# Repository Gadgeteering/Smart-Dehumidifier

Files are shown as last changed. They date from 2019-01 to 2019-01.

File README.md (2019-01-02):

# Smart-Dehumidifier

This project modifies a Demuidifier into a Smart Dehumidifier so that it is automatically turned on when it is predicted that condensation will form on a window pane.


More details of project are available here

https://www.instructables.com/id/Dehumidifier/

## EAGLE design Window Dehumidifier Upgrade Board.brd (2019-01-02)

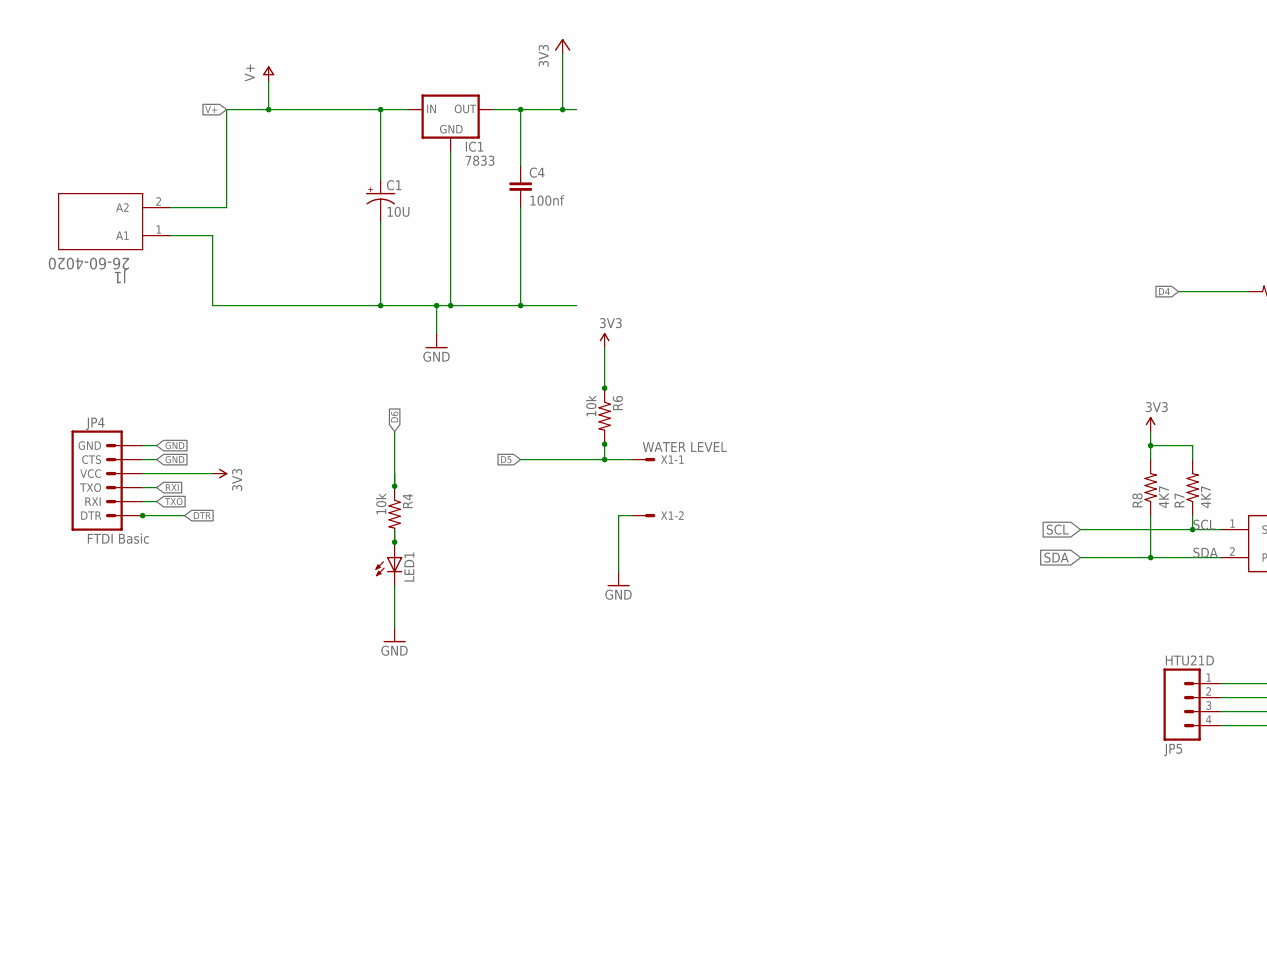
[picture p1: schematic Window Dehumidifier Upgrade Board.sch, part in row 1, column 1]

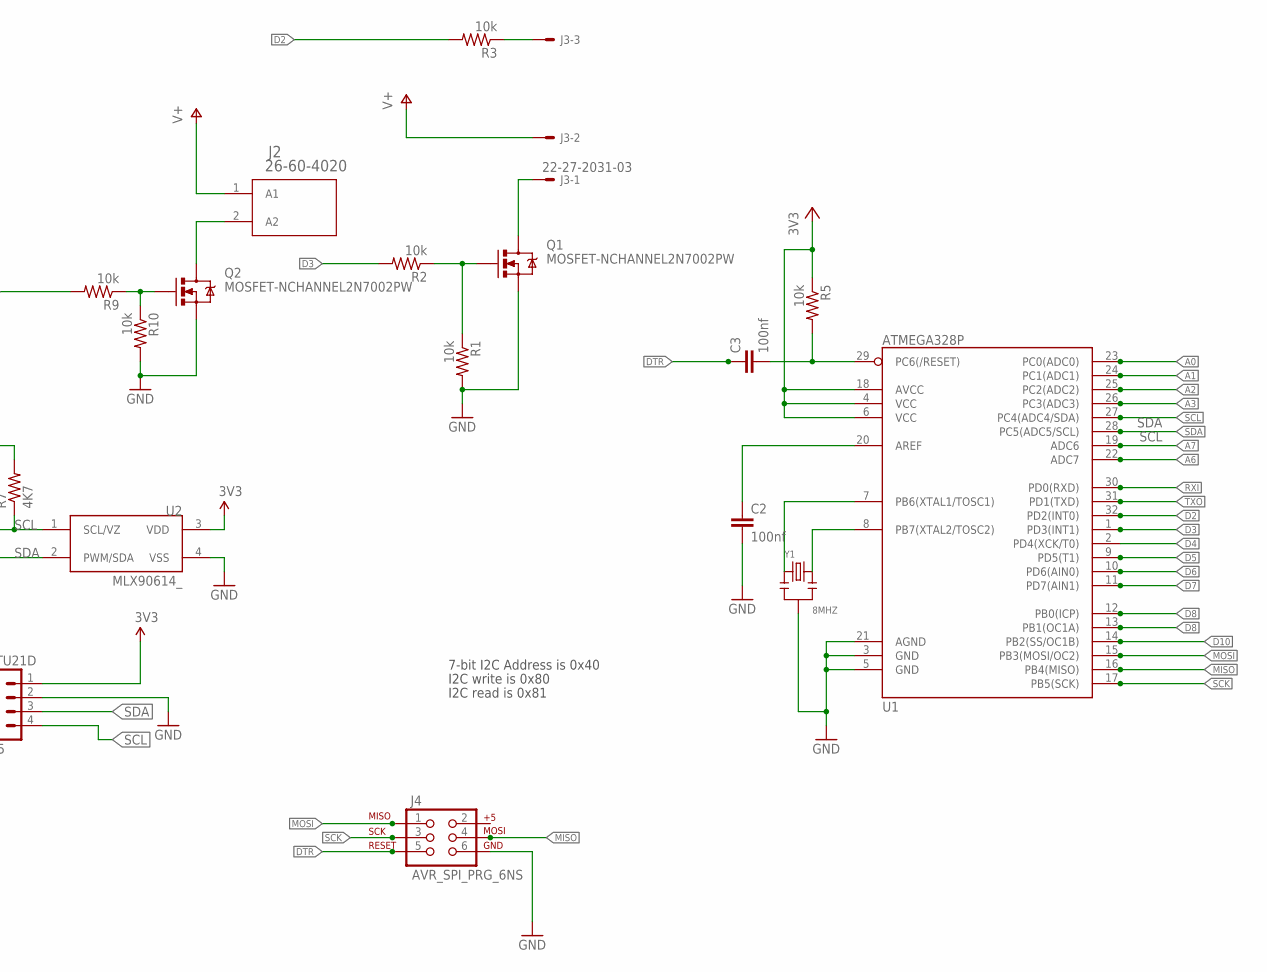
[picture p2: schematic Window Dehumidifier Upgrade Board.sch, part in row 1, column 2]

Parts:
C1: 10U; CPOL-RADIAL-100UF-25V
C2, C3, C4: 100nf; 0805
IC1: 7833; TO-92
J1, J2: 26-60-4020
J3: 22-27-2031-03; 6410-03
J4: AVR_SPI_PRG_6NS; 2X3-NS
JP4: FTDI Basic; 1X06
JP5: HTU21D; 1X04
LED1: LED3MM
Q1, Q2: MOSFET-NCHANNEL2N7002PW; SOT323
R1, R2, R3, R4, R5, R6, R9, R10: 10k; 0805
R7, R8: 4K7; 0805
U1: ATMEGA328P; TQFP32-08
U2: MLX90614_; TO-39
X1: WATER LEVEL; 22-23-2021
Y1: 8MHZ; X3-2.5-8X3X5.5MM

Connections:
3.3V: JP4.4 (VCC)
3V3: C4.1, IC1.3 (OUT), JP5.1, R5.1, R6.1, R7.2, R8.2, U1.4 (VCC), U1.6 (VCC), U1.18 (AVCC), U2.3 (VDD)
A0: U1.23 (PC0(ADC0))
A1: U1.24 (PC1(ADC1))
A2: U1.25 (PC2(ADC2))
A3: U1.26 (PC3(ADC3))
A6: U1.22 (ADC7)
A7: U1.19 (ADC6)
D2: R3.2, U1.32 (PD2(INT0))
D3: R2.2, U1.1 (PD3(INT1))
D4: R9.2, U1.2 (PD4(XCK/T0))
D5: R6.2, U1.9 (PD5(T1)), X1.1
D6: R4.1, U1.10 (PD6(AIN0))
D7: U1.11 (PD7(AIN1))
D8: U1.12 (PB0(ICP))
D9: U1.13 (PB1(OC1A))
D10: U1.14 (PB2(SS/OC1B))
DTR: C3.1, J4.5, JP4.1 (DTR)
GND: C1.2 (-), C2.2, C4.2, IC1.1 (GND), J1.1 (A1), J4.6, JP4.5 (CTS), JP4.6 (GND), JP5.2, LED1.K (C), Q1.2 (S), Q2.2 (S), R1.2, R10.2, U1.3 (GND), U1.5 (GND), U1.21 (AGND), U2.4 (VSS), X1.2, Y1.2
MISO: J4.4, U1.16 (PB4(MISO))
MOSI: J4.1, U1.15 (PB3(MOSI/OC2))
unnamed: Q2.1 (G), R9.1, R10.1
unnamed: J2.2 (A2), Q2.3 (D)
unnamed: Q1.1 (G), R1.1, R2.1
unnamed: J3.1, Q1.3 (D)
unnamed: LED1.A, R4.2
unnamed: J3.3, R3.1
unnamed: C2.1, U1.20 (AREF)
unnamed: C3.2, R5.2, U1.29 (PC6(/RESET))
unnamed: U1.7 (PB6(XTAL1/TOSC1)), Y1.1
unnamed: U1.8 (PB7(XTAL2/TOSC2)), Y1.3
RXI: JP4.3 (TXO), U1.30 (PD0(RXD))
SCK: J4.3, U1.17 (PB5(SCK))
SCL: JP5.4, R7.1, U1.28 (PC5(ADC5/SCL)), U2.1 (SCL/VZ)
SDA: JP5.3, R8.1, U1.27 (PC4(ADC4/SDA)), U2.2 (PWM/SDA)
TXO: JP4.2 (RXI), U1.31 (PD1(TXD))
V+: C1.1 (+), IC1.2 (IN), J1.2 (A2), J2.1 (A1), J3.2

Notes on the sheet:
7-bit I2C Address is 0x40
I2C write is 0x80
I2C read is 0x81

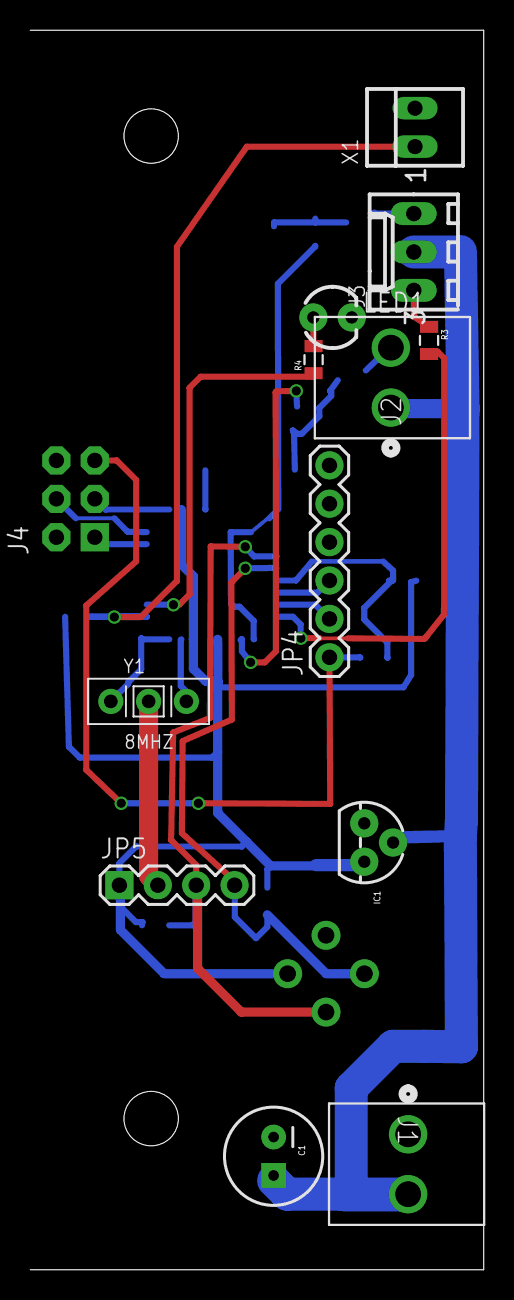
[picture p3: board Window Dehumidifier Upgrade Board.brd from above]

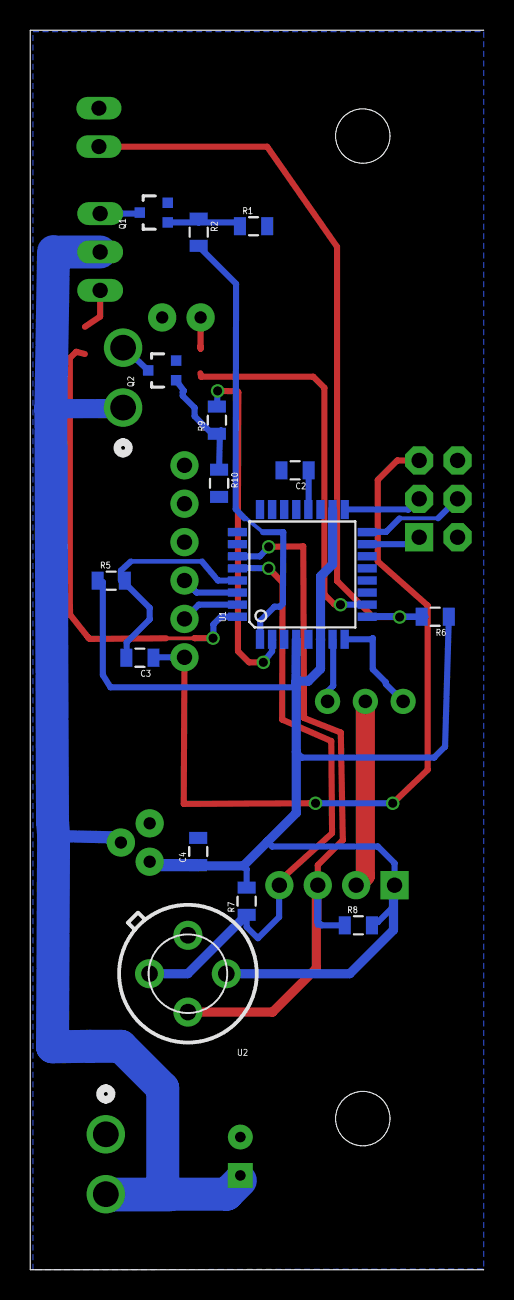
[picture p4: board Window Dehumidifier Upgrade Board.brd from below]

Board: 2 copper layers, 30.0 x 82.0 mm, 28 parts (15 on the bottom side), 26 nets.

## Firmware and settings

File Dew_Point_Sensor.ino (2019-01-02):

#include <Wire.h>
#include <Adafruit_MLX90614.h>
//#include "SparkFunHTU21D.h"
#include "Adafruit_HTU21DF.h"
#include <movingAvg.h>

Adafruit_MLX90614 mlx = Adafruit_MLX90614();
//Create an instance of the object
//HTU21D myHumidity;
Adafruit_HTU21DF myHumidity = Adafruit_HTU21DF();

const long oneSecond = 1000;  // a second is a thousand milliseconds
const long oneMinute = oneSecond * 60;
const long oneHour   = oneMinute * 60;
const long oneDay    = oneHour * 24;

const int analogOutPin = 12; // Analog output pin that the motor is attached to
const int LED = 6; //Led Pin
const int Water_Sensor=5;
const int Heat_Ex=4;
const int Fan=3;
const int Fan_Sensor = 2;
int Fan_Speed;
int outputValue = 0;        // value output to the PWM (analog out)
int ObjectTempOffset =5; //Window temp offset + differential below top and bottom of glass
boolean motor_running;

unsigned long previousMillis,currentMillis;
int interval=1000;

movingAvg avgATemp(10);                  // define the moving average object
movingAvg avgHumid(10);                  // define the moving average object
movingAvg avgOTemp(10);                  // define the moving average object
void setup() {
  
  motor_running =false;
  Serial.begin(57600);
  Serial.println("Adafruit MLX90614 test");  
  myHumidity.begin();
  mlx.begin();  
  avgATemp.begin();                            // initialize the moving average
  avgOTemp.begin();                            // initialize the moving average
  avgHumid.begin();                            // initialize the moving average
  pinMode(Fan,OUTPUT);
  
  pinMode(Heat_Ex,OUTPUT);
  pinMode(Water_Sensor,INPUT);
  pinMode(Fan_Sensor,INPUT);
  pinMode(LED,OUTPUT);
  
}


void loop() {

  // put your main code here, to run repeatedly:
 float AmbientTemp = mlx.readAmbientTempC(); 
 //Serial.print("Ambient = "); Serial.print(AmbientTemp);
 float readObjectTemp = mlx.readObjectTempC(); 
 //readObjectTemp = avgOTemp.reading(readObjectTemp);             // calculate the moving average

  float humd = myHumidity.readHumidity();
  //humd = avgHumid.reading(humd);             // calculate the moving average
  float temp = myHumidity.readTemperature();
  //temp = avgATemp.reading(temp);             // calculate the moving average
  float dewp= temp-((100-humd)/5);


unsigned long currentMillis = millis();
if ((unsigned long)(currentMillis - previousMillis) >= interval) {
  Serial.print(" MLX Air Temp");
  Serial.print(AmbientTemp,1);
  Serial.print(" ");
  Serial.print("*C Object = "); Serial.print(readObjectTemp);
  Serial.print(" HTU21D Air Temp: ");
  Serial.print(temp, 1);
  Serial.print("C");
  Serial.print(" ");
  Serial.print(" Humidity:");
  Serial.print(humd, 1);
  Serial.print("% ");
  Serial.print("Dew Point: ");
  Serial.print(dewp,1);
  Serial.print("C");
  Serial.println();
  previousMillis = currentMillis;

  
  if ((readObjectTemp-ObjectTempOffset) <dewp)
  {
    motor_running = true;
    Serial.print("All On");
  }
 
  
 if (readObjectTemp-(ObjectTempOffset+1)>dewp)
      {
        motor_running = false;
        Serial.print("All Off");
      }

Fan_Speed=digitalRead(Fan_Sensor);
Serial.print("Fan Sensor="+Fan_Speed);
if( digitalRead(Water_Sensor)==false)   {
    digitalWrite(LED,LOW);
 if(motor_running == false){
    digitalWrite(Fan,0);
    digitalWrite(Heat_Ex,0);
    Serial.print("Fan Heat Ex. off");
   
    Serial.print("Time:");
    
  
   
    
   }
 if(motor_running == true){
  
     digitalWrite(Fan,1);
    digitalWrite(Heat_Ex,1);
   
   }
}
else
{ Serial.print("Water_Sensor true all Off");
digitalWrite(Fan,0);
digitalWrite(Heat_Ex,0);
digitalWrite(LED,HIGH);
}
   Serial.println();
}
  
}

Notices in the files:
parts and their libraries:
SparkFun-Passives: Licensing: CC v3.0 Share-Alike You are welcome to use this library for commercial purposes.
